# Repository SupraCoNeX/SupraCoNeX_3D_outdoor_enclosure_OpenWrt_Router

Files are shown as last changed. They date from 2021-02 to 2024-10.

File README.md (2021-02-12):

# SupraCoNeX 3D Enclosure for OpenWrt Routers

## Open-source & open-hardware 3D outdoor/indoor enclosure for OpenWrt routers.

```                                                                                                 
  .--,-``-.                                                                                  
 /   /     '.      ,---,              .--.--.                                                
/ ../        ;   .'  .' `\           /  /    '.               ,-.----.                       
\ ``\  .`-    ',---.'     \         |  :  /`. /          ,--, \    /  \   __  ,-.            
 \___\/   \   :|   |  .`\  |        ;  |  |--`         ,'_ /| |   :    |,' ,'/ /|            
      \   :   |:   : |  '  |        |  :  ;_      .--. |  | : |   | .\ :'  | |' | ,--.--.    
      /  /   / |   ' '  ;  :         \  \    `. ,'_ /| :  . | .   : |: ||  |   ,'/       \   
      \  \   \ '   | ;  .  |          `----.   \|  ' | |  . . |   |  \ :'  :  / .--.  .-. |  
  ___ /   :   ||   | :  |  '          __ \  \  ||  | ' |  | | |   : .  ||  | '   \__\/: . .  
 /   /\   /   :'   : | /  ;          /  /`--'  /:  | : ;  ; | :     |`-';  : |   ," .--.; |  
/ ,,/  ',-    .|   | '` ,/          '--'.     / '  :  `--'   \:   : :   |  , ;  /  /  ,.  |  
\ ''\        ; ;   :  .'              `--'---'  :  ,      .-./|   | :    ---'  ;  :   .'   \ 
 \   \     .'  |   ,.'                           `--`----'    `---'.|          |  ,     .-./ 
  `--`-,,-'    '---'                                            `---`           `--`---'                                                                                           
```

*__What are our Enclosure Design Goals:__*
 * DIY printable outdoor enclosure
 * easy mountable on (a) roof top poles and (b) walls with an adapter board
 * as srewless as possible
 * weatherproof for outdoor usage
 * be modular where it's worth:
   * support different router boards and setups -> common board plate API
   * support different cable gland setups for RF and Ethernet
   * support different logos

*__List of supported OpenWrt routers:__*
 * BananaPi R64 (with mt7615, etc.)
 * ...

*__Pictures of the Enclosure:__*

*inside*


*outside*


*backside*




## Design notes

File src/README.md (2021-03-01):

Prusa Settings

- draft-mode
- 0.3
- supports only on printbed
- bottom layers: 2
- top layers: 2
- outline / walls / contour: 2
- support for bridges - disabled
- infill: mesh / grid 20%

Rest: 
- default for draft-mode

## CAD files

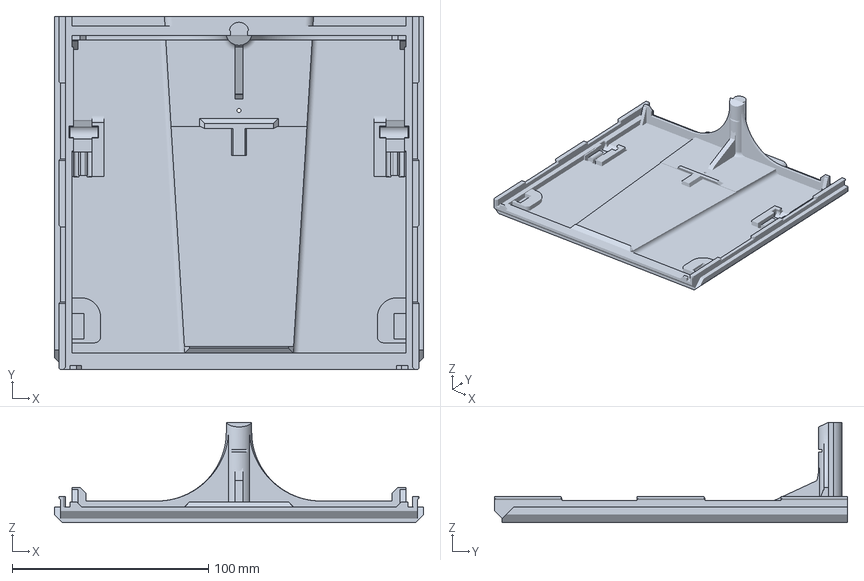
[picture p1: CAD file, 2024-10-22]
src/3mf/scnx_housing_2024_Boden_2.2_reinforced_pole_hinge_2.3mf
188.0 x 180.0 x 51.0 mm

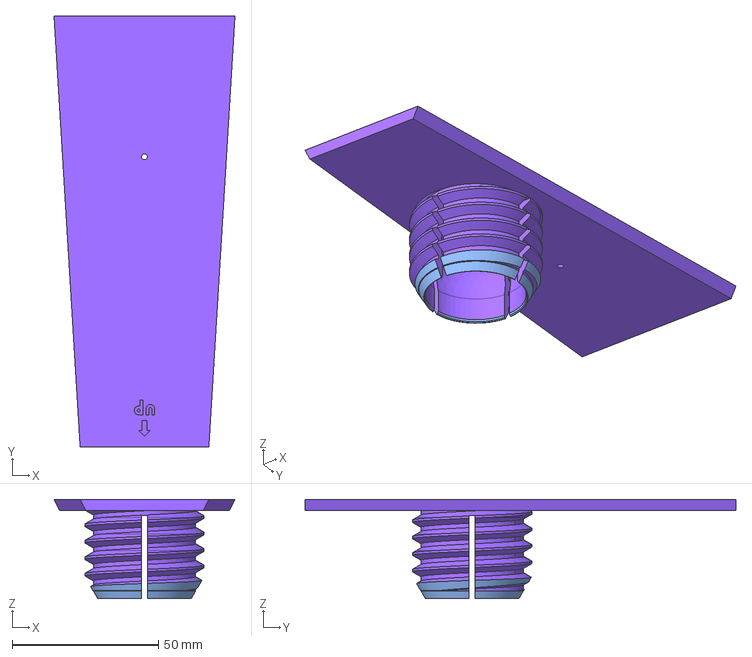
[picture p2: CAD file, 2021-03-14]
src/step/scnx_ballmount_base_pot.step
61.8 x 147.0 x 33.9 mm

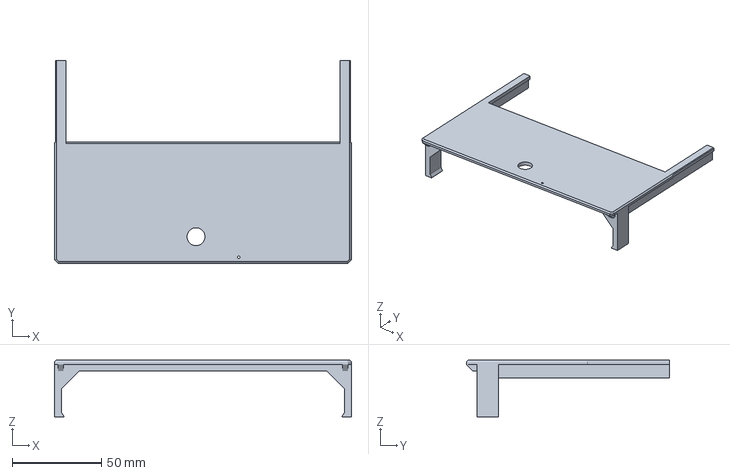
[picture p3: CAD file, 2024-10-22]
src/3mf/scnx_housing_2024_Internal_antenna_table_hinge_2.3mf
166.0 x 113.5 x 31.8 mm

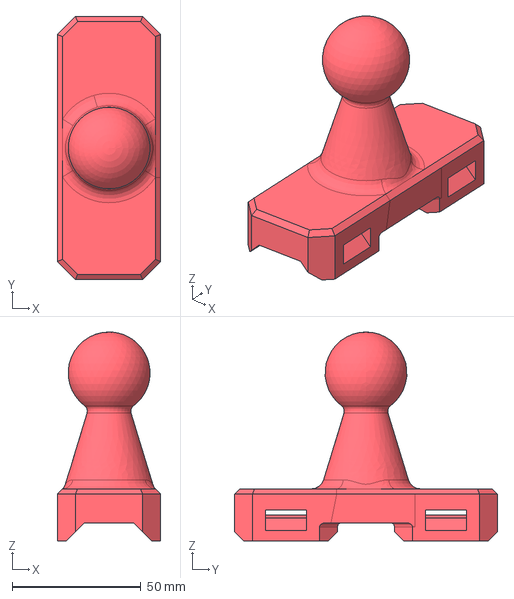
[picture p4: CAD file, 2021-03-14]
src/step/scnx_ballmount_ball.step
40.0 x 102.0 x 81.0 mm

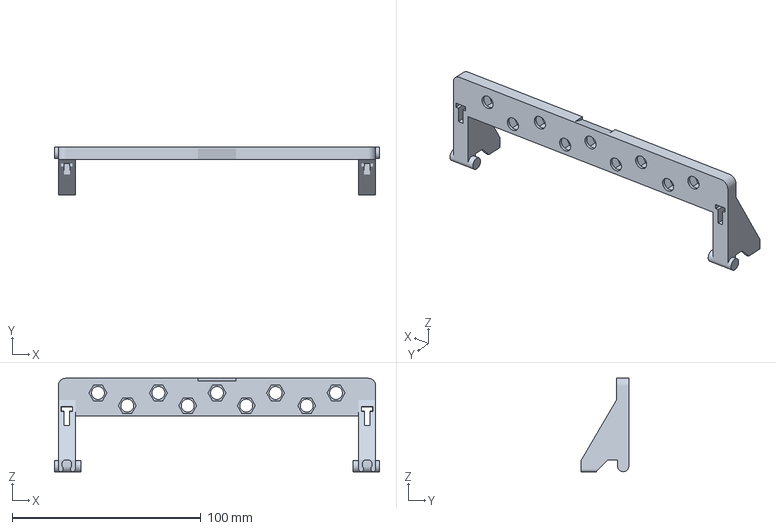
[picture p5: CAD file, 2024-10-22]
src/3mf/scnx_housing_2024_Antennenbügel 9hole_axle_2.3mf
172.0 x 25.2 x 49.5 mm

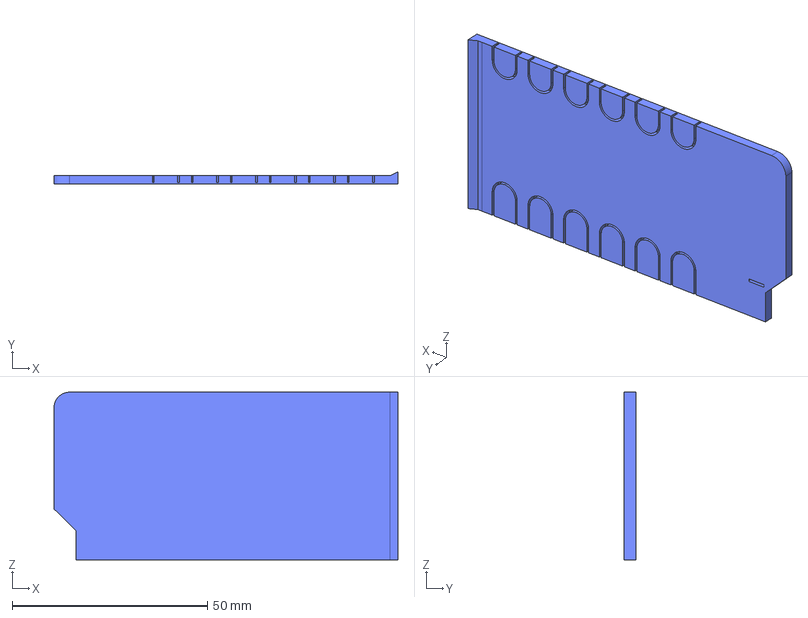
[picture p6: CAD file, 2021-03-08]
src/step/scnx_splash_guard_l.step
88.2 x 3.20 x 43.0 mm

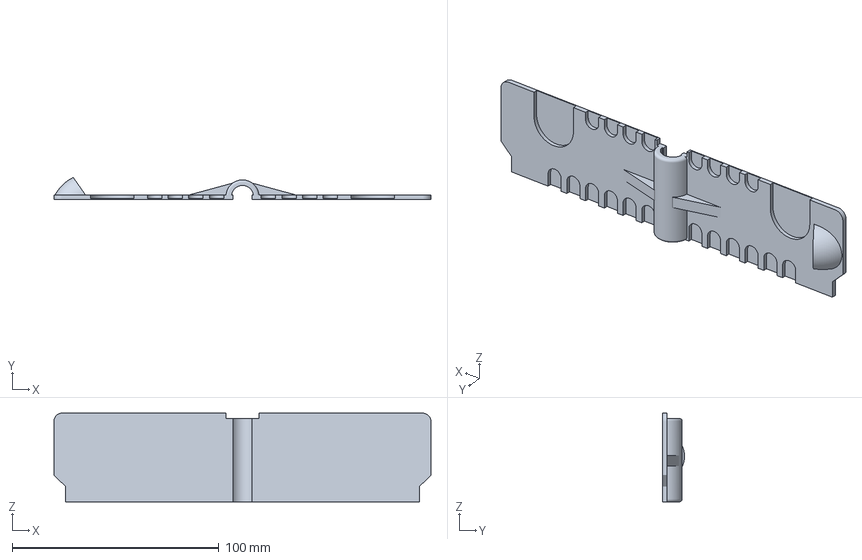
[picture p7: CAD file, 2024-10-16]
src/3mf/scnx_housing_2024_splash_guard.3mf
182.2 x 10.7 x 42.9 mm

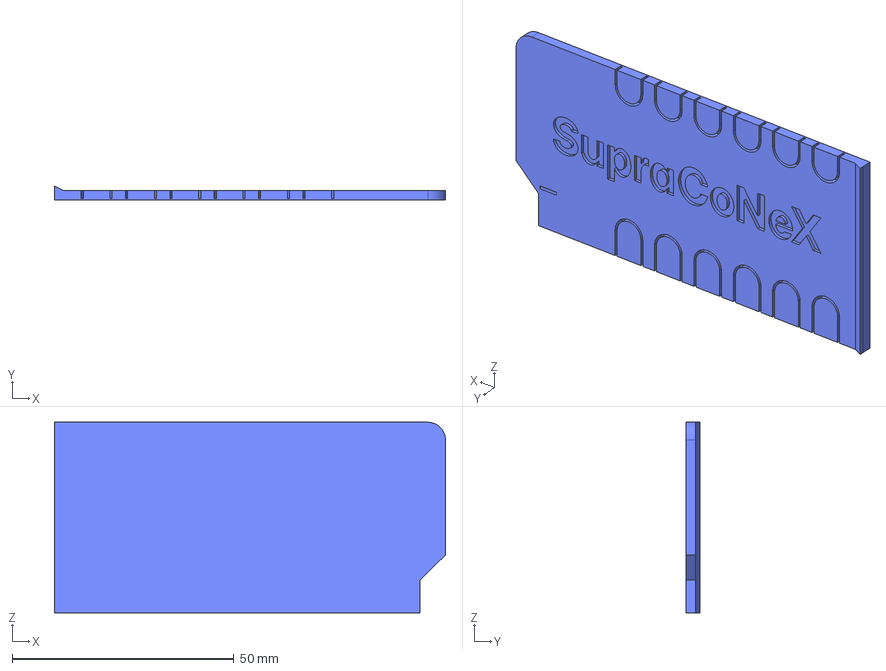
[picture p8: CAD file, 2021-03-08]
src/step/scnx_splash_guard_r.step
88.2 x 3.20 x 43.0 mm

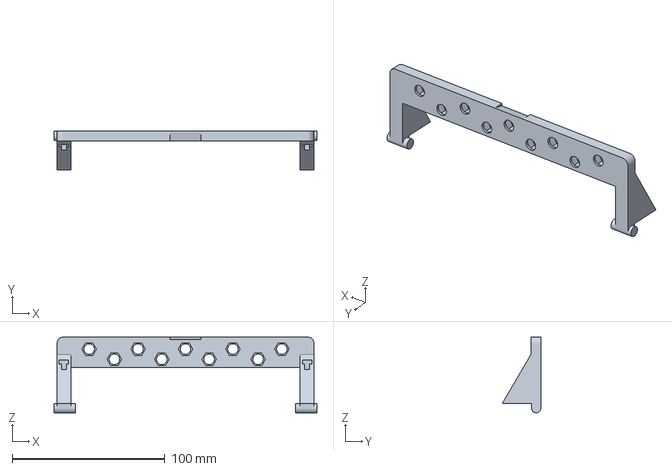
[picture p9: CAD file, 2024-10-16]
src/3mf/scnx_housing_2024_Antennenbügel 9hole_axle.3mf
172.0 x 25.2 x 49.5 mm

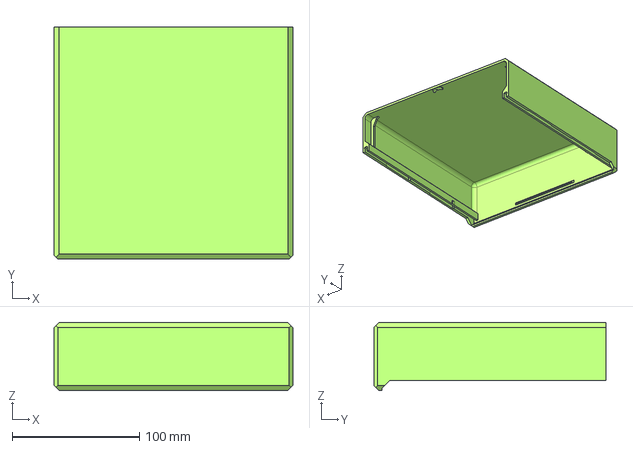
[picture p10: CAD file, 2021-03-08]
src/step/scnx_top_cover.step
188.0 x 182.6 x 53.6 mm

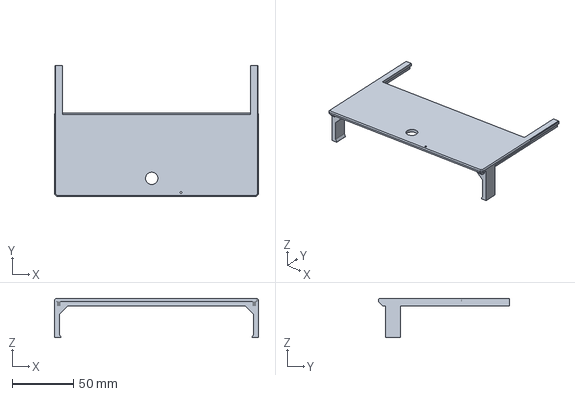
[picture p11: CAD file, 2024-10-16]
src/3mf/scnx_housing_2024_Internal_antenna_table_hinge.3mf
166.0 x 107.0 x 31.8 mm

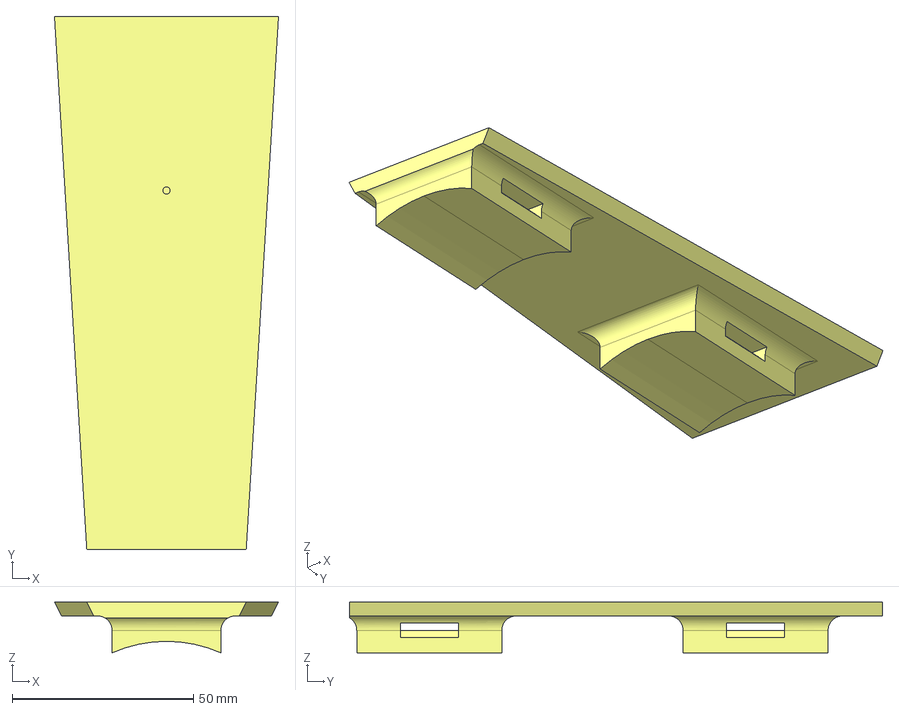
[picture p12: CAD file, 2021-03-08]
src/step/scnx_pole_mount.step
61.8 x 147.0 x 14.0 mm

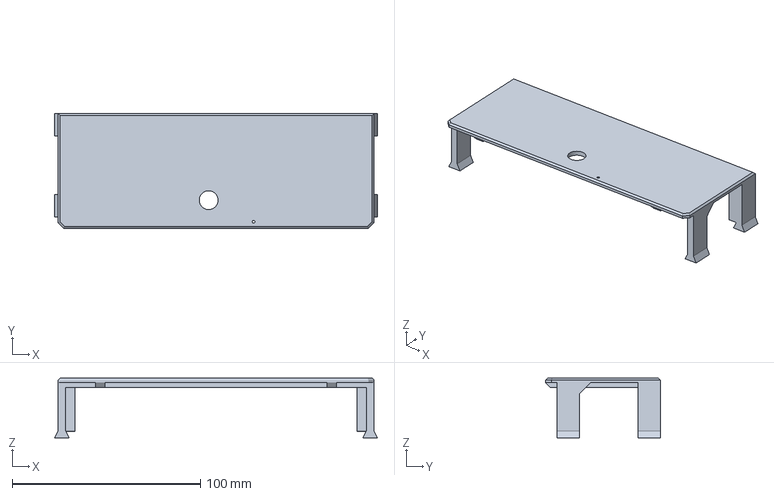
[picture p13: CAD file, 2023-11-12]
src/3mf/scnx_housing_Internal_antenna_table_no_ears.3mf
171.8 x 61.0 x 31.9 mm

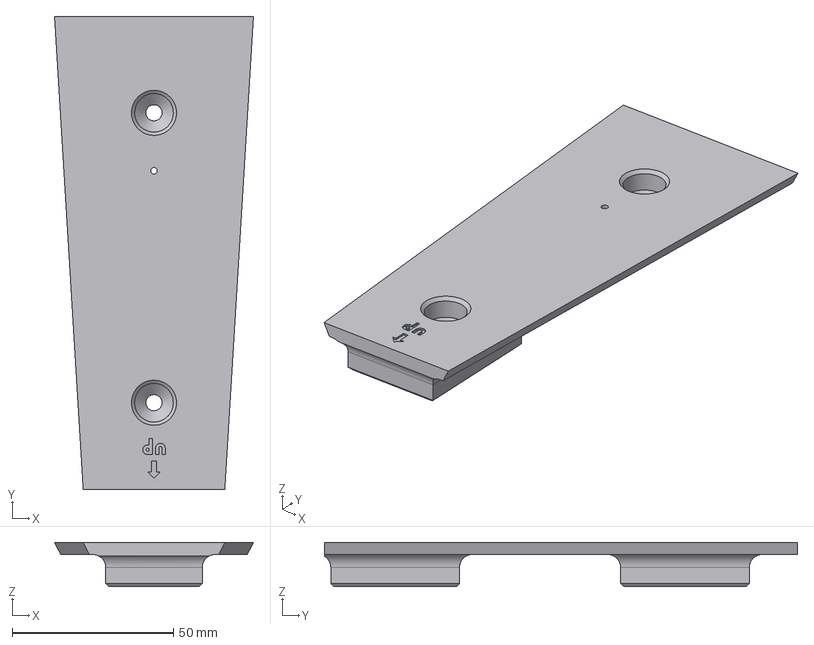
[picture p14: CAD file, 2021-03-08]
src/step/scnx_wall_mount.step
61.8 x 147.0 x 13.8 mm

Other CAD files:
src/3mf/scnx_housing_2024_ground_plate.3mf
src/3mf/scnx_housing_ Boden_2.1_reinforced_pole.3mf
src/step/scnx_pigtail_bracket_9hole.step
src/3mf/scnx_housing_ Boden_2.1_reinforced_pole_triangles.3mf
src/3mf/scnx_ball_mount_v3.3mf
src/3mf/scnx_ground_plate.3mf
src/3mf/scnx_housing_ground_plate_2.0.3mf
src/3mf/scnx_housing_ground_plate_2.0_with_nose.3mf
src/3mf/scnx_housing_topcover_2.0.3mf
src/3mf/scnx_housing_wall_pole_mount_35.3mf
src/3mf/scnx_housing_wall_pole_mount_50_2.0.3mf
src/3mf/scnx_internal_antenna_pole_L.3mf
src/3mf/scnx_internal_antenna_pole_R.3mf
src/3mf/scnx_internal_antenna_table.3mf
src/3mf/scnx_internal_antenna_table_ears.3mf
src/3mf/scnx_pcb_mounting_plate.3mf
src/3mf/scnx_pigtail_bracket_4hole.3mf
src/3mf/scnx_pigtail_bracket_9hole.3mf
src/3mf/scnx_pole_mount.3mf
src/3mf/scnx_splash_guard.3mf
src/3mf/scnx_top_cover_waterlip.3mf
src/3mf/scnx_wall_mount.3mf
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

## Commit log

2021-02-11 add initial SupraCoNeX enclosure design
    - outdoor enclosure
    - banana-pi64
    [scnx_ground_plate.step, scnx_logo_letters.step, scnx_pcb_mounting_plate.step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]
2021-02-12 add picture of open enclosure
2021-02-12 add picture of closed enclosure
2021-02-12 enclosure enhancements
    - adjust pigtail_bracket for diplexer
    - snap-in groove for pigtail bracket
    - slope for lid holder
    - screw hole for pole_mount
    [scnx_ground_plate.step, scnx_logo_letters.step, scnx_pcb_mounting_plate.step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]
2021-02-12 initial upload STL
    improved enclosure stl upload
    [scnx_ground_plate.stl, scnx_logo_letters.stl, scnx_pcb_mounting_plate.stl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]
2021-02-15 added 9 hole
    pigtail_bracket with 9 holes added
    [scnx_pigtail_bracket_9hole.step, scnx_pigtail_bracket_9hole.stl]
2021-02-15 added wall_mount
    wall_mount uploaded
    [scnx_wall_mount.step, scnx_wall_mount.stl]
2021-02-16 fix stl file
    removed additional object from stl
    [scnx_pigtail_bracket_9hole.step, scnx_pigtail_bracket_9hole.stl]
2021-03-01 updated parts
    - new cover
    - new bottom
    - new splash_guard
    [scnx_ground_plate.stl, scnx_spash_guard.stl, scnx_splash_guard.stl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]
2021-03-08 update for internal antenna table
    added Slide-in units for internal antenna table
    [scnx_ground_plate.step, scnx_ground_plate.stl]
2021-03-08 new part added
    new part to glue pcb antenna on it
    [scnx_internal_antenna_table.step, scnx_internal_antenna_table.stl]
2021-03-08 updated parts
    small bevel added to slide TopCover
    [scnx_pigtail_bracket.step, scnx_pigtail_bracket.stl, scnx_pigtail_bracket_9hole.step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]
2021-03-08 updated parts
    Part slightly shortened so that the insertion fits tightly
    [scnx_pole_mount.step, scnx_pole_mount.stl, scnx_wall_mount.step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]
2021-03-08 updated part
    increased wall thickness
    [scnx_top_cover.step, scnx_top_cover.stl]
2021-03-08 updated parts
    parts updated to fit and hold in place
    [scnx_splash_guard.step, scnx_splash_guard.stl, scnx_splash_guard_l.step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]
2021-03-14 variable ballmount added
    added new component to mount the case in variable angles
    [scnx_ballmount_ball.step, scnx_ballmount_ball.stl, scnx_ballmount_base_pot.step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]
2021-11-26 Add files via upload
    files updated - thicker pigtail, ears on antenna table
    [scnx_internal_antenna_table.3mf, scnx_internal_antenna_table.stl, scnx_pigtail_bracket_9hole.3mf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]
2021-11-26 create 3mf dircetory to support this open 3D format
    [scnx_internal_antenna_table.3mf, scnx_pigtail_bracket_9hole.3mf]
2021-12-19 Files updated, reinforcements + improvements
    [scnx_Internal_antenna_pole_L.stl, scnx_Internal_antenna_pole_R.stl, scnx_ground_plate.stl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]
2021-12-19 Updated files, reinforcements + improvements
    [scnx_Internal_antenna_pole_L.3mf, scnx_Internal_antenna_pole_R.3mf, scnx_ground_plate.3mf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]
2022-03-20 new versions in several files - improvements
    [scnx_ball_mount_v3.3mf, scnx_ground_plate.3mf, scnx_internal_antenna_pole_L.3mf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]
2022-06-27 Updated housing 2.0
    [SCNX housing groundplate2.0.3mf, SCNX housing topcover2.0.3mf, SCNX housing wall pole mount2.0.3mf]
2022-06-27 fix wrong file nameing
    [SCNX housing groundplate2.0.3mf, SCNX housing topcover2.0.3mf, SCNX housing wall pole mount2.0.3mf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]
2022-07-11 improvements on housing parts
    [scnx_housing_ground_plate_2.0.3mf, scnx_housing_splashguard_2.0.3mf, scnx_housing_topcover_2.0.3mf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]
2022-08-27 groundplate with click nose
    [scnx_housing_ scnx_housing_ground_plate_2.0_with_nose.3mf]
2022-08-27 groundplate with click nose correct name
    [scnx_housing_ground_plate_2.0_with_nose.3mf]
2023-03-25 update top cover with enlarged click holder to increase closure force
    [scnx_internal_antenna_table_ears.3mf, scnx_pigtail_bracket_4hole.3mf, scnx_splash_guard.3mf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]
2023-03-25 adapt spalsh holder for new cover nibble high
    [scnx_pigtail_bracket_9hole.3mf]
2023-03-25 add new pole-wall mount with 35mm roudning to avoid cracking
    [scnx_housing_wall_pole_mount_35.3mf]
2023-04-04 picktail_bracket and antenna_table adjusted
    reduced space between parts and groundplate
    [scnx_internal_antenna_table_ears.3mf, scnx_pigtail_bracket_9hole.3mf]
2023-10-01 teinforces pole on groundplate by two methods
    [scnx_housing_ Boden_2.1_reinforced_pole.3mf, scnx_housing_ Boden_2.1_reinforced_pole_triangles.3mf]
2023-10-01 reinforced pole on groundplate by two methods
    [scnx_housing_ Boden_2.1_reinforced_pole.3mf, scnx_housing_ Boden_2.1_reinforced_pole_triangles.3mf]
2023-11-12 new design changes:
    -no ears antenna table added
    -splash guard adapted to handle large low loss cable
    [scnx_housing_Internal_antenna_table_no_ears.3mf, scnx_housing_splashguard_2.0.3mf, scnx_splash_guard.3mf]
2024-10-16 added three files 2024
    Groundplate with hinge-construction
    Picktailbracket with axle
    connectable internal antenna table
    [scnx_housing_2024_Antennenbügel 9hole_axle.3mf, scnx_housing_2024_Boden_2.2_reinforced_pole_hinge.3mf, scnx_housing_2024_Internal_antenna_table_hinge.3mf]
2024-10-16 splash guard
    with easy removeable curtains
    [scnx_housing_2024_splash_guard.3mf]
2024-10-16 Ground plate with hinge
    [scnx_housing_2024_ground_plate.3mf]
2024-10-22 imporved hinge and lock
    [scnx_housing_2024_Antennenbügel 9hole_axle_2.3mf, scnx_housing_2024_Boden_2.2_reinforced_pole_hinge_2.3mf, scnx_housing_2024_Internal_antenna_table_hinge_2.3mf]

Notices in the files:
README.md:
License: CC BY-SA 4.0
